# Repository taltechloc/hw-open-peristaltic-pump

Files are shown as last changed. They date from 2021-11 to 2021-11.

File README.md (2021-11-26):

# Open peristaltic microfluidic pump

## Features:
- Peristaltic pump
- Cheap and easy to assemble
- Wireless control
- Battery power

*Designed by: Martin Grosberg.*
*Please be kind and cite me if you use my designs:*
- Original source: Low-cost wireless smart microfluidic pump based on [Martin Grosberg's thesis](https://digikogu.taltech.ee/et/Item/b4fc732c-1057-41ed-a8f3-72b04feb9e4f).

## Construction and use

Folders: 
- Documentation: **Please read the user manual under the Documentation folder first!**
- Electronics: schematics and BOM
- Firmware: Arduino source code
- Mechanical: STL files for 3D printing. Use an FDM printer such as a [Prusa](https://www.prusa3d.com/category/3d-printers/). 

Please note that we cannot offer support or take responsibility for damage caused by using this product.

---


*This is an OSHW project*

OSHW logo

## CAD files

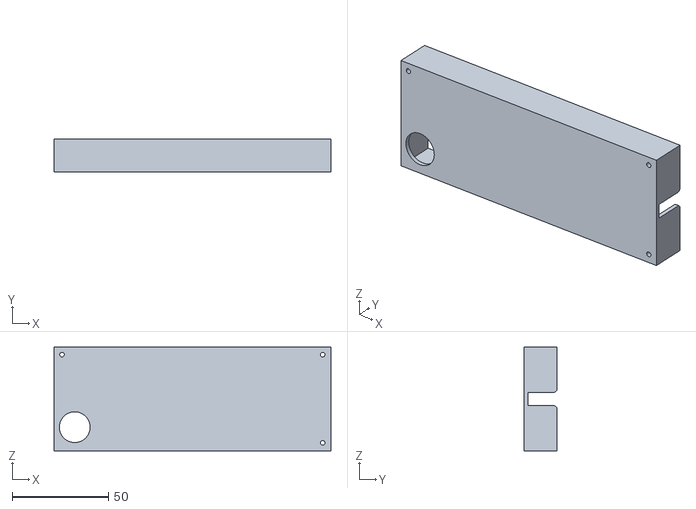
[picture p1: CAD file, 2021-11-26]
Mechanical/3D printing files/Flow sensor enclousure v8.STL
144.0 x 17.0 x 54.0

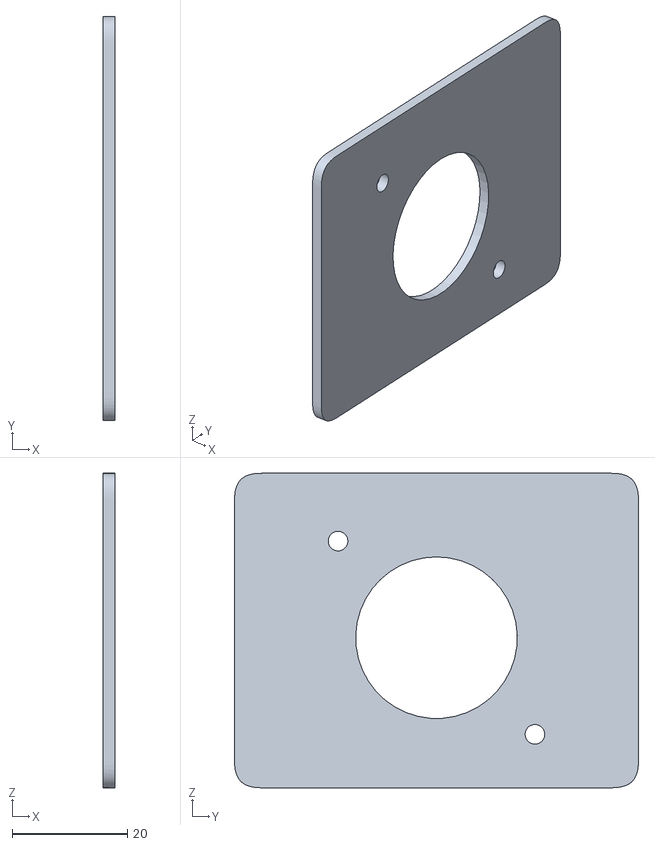
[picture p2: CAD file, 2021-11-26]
Mechanical/3D printing files/Motor plate.STL
2.00 x 70.0 x 54.5

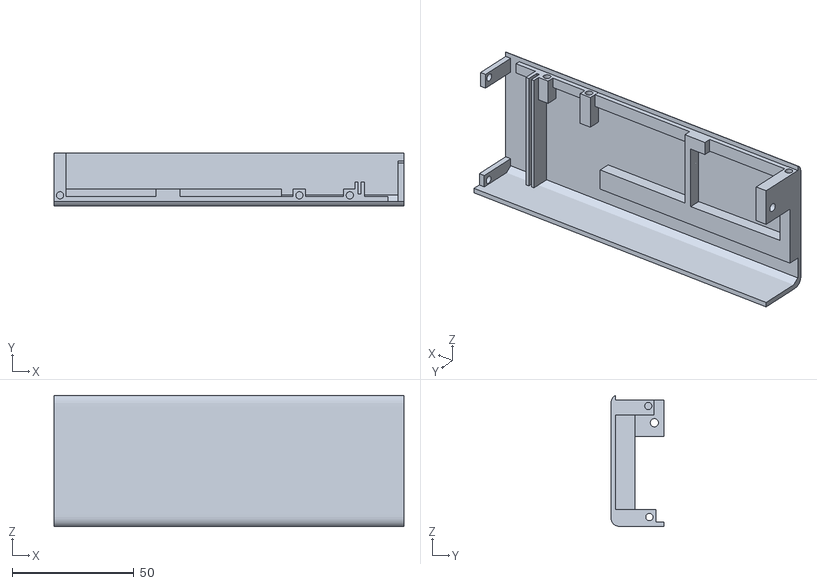
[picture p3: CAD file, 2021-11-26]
Mechanical/3D printing files/Electronics casing.STL
144.0 x 22.0 x 54.0

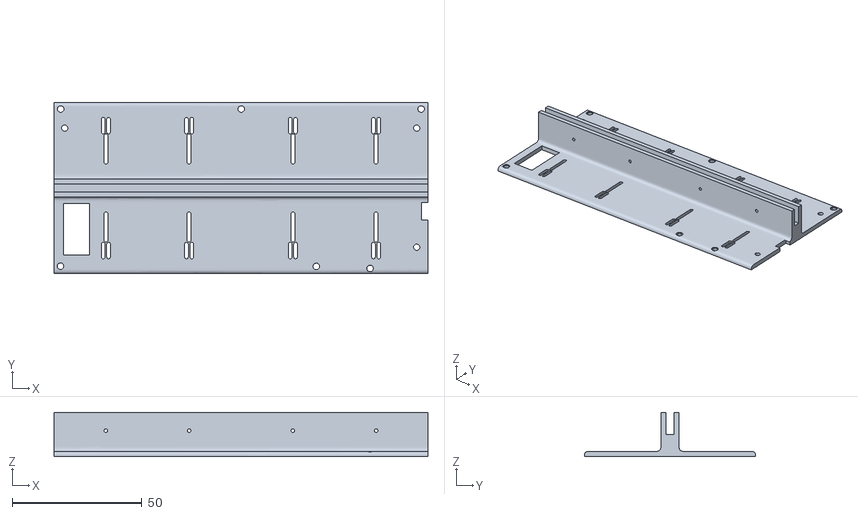
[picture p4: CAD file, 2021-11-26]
Mechanical/3D printing files/Front panel v8.STL
144.0 x 66.0 x 17.0

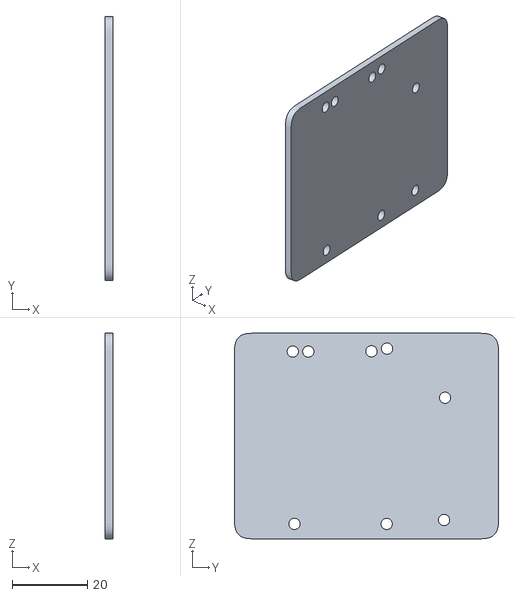
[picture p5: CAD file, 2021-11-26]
Mechanical/3D printing files/case v8.STL
2.00 x 70.0 x 54.5

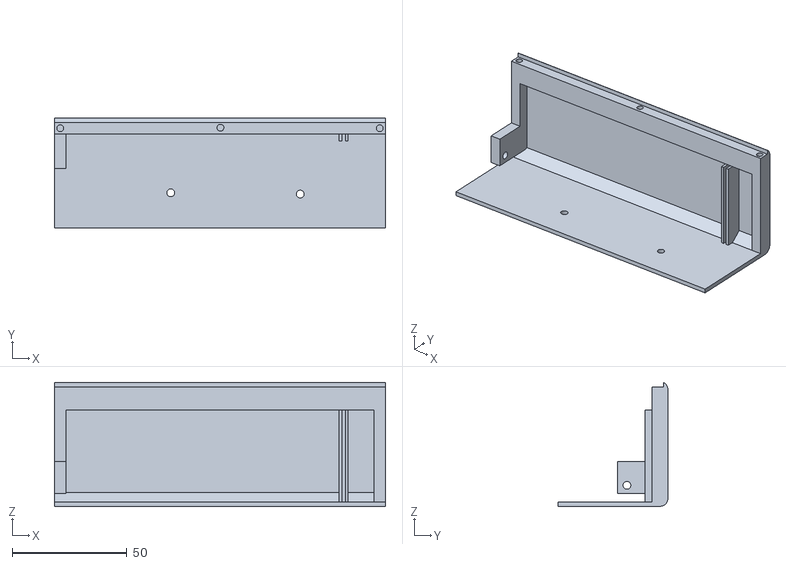
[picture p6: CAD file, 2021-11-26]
Mechanical/3D printing files/Casing.STL
144.0 x 48.0 x 54.0

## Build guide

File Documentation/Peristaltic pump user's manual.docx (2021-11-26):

Peristaltic pump

User’s Manual

# 1. Package contents

- 1. ESP32 DevkitC controller
- 2. Adafruit peristaltic pump
- 3. 18650 3.6V 3350 mAh Lithium-ion battery (2pcs), 18650 double battery holder
- 4. LM2596 DC/DC buck regulator
- 5. LM2577 DC/DC step up module
- 6. Prototyping board, 1N4007 rectifier diode, 2 1k resistors, 10k resistor, LMC7101 opamp, IRF520N MOSFET (Components needs to be soldered together).
- 7. ON-OFF button
- 8. headers and pins
- 9. Wires
- 10. Bolts and nuts
- 11. 3D printed enclousre

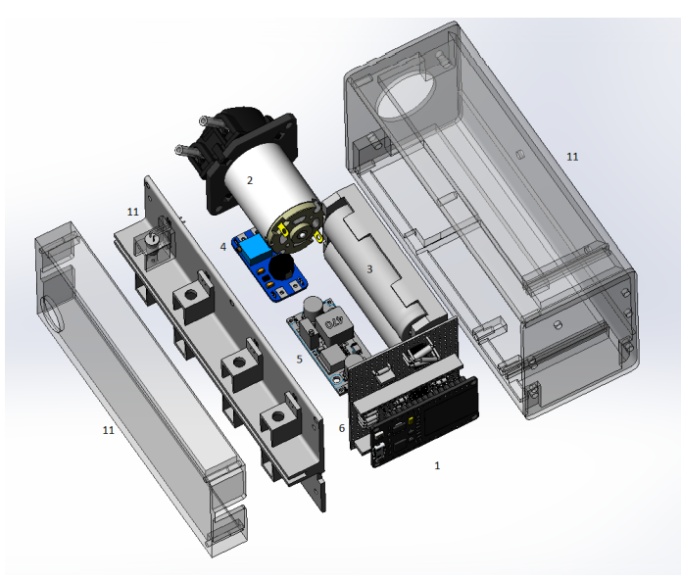
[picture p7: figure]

# 2. Safety precautions

- Solder the prototyping board components according to the schematics.
- Do wiring so that they will not becaume loose or short circuit the board.
- Upload the code through cable to the ESP32 devkitC controller. For safety reasons don’t have it connected with external batteries while uploading the code.
- Connect the EPS32 DevkitC controller right way on the prototyping board otherwise the board will get damaged.
- The batteries are connected parallel so the device usage time will be longer.
- When batteries are empty remove the case carefully and put them to charging station. After fully charged connect them them the right way. It’s good to put some polarity stickers to battery holder.

# 3. Features

- User Interface over Wi-Fi AP
- Possible to add two slave pumps
- Timer function

# 4. Technical description

- Flow rate 12-72 ml/min
- Tubing ID: 1mm
- Runtime 10-15min at max flow rate
- Power ON/OFF
- 18650 lithium-ion batteries (2pcs)
- Dimensions: 70x71,50x174,20(mm)

# 5. Connection and operation

- Before operating be sure to have fully charged batteries. In order to charge it’s needed to open the device enclousure. The charging station is not included. When putting back batteries, then the batteries are connected in parallel.
- Turn the pump on from ON/OFF button
- Use a laptop or mobile phone and connect to „SmartFlowController2“.
- Enter password: „Taltech2020“
- Set the flow rate and pumping time.
- Connect one tubing to reservoir and the 2nd tube end to the lab-on-the-chip.
- When you have a slave pump, then it’s possible to add it int the interface by entering the MAC ID.

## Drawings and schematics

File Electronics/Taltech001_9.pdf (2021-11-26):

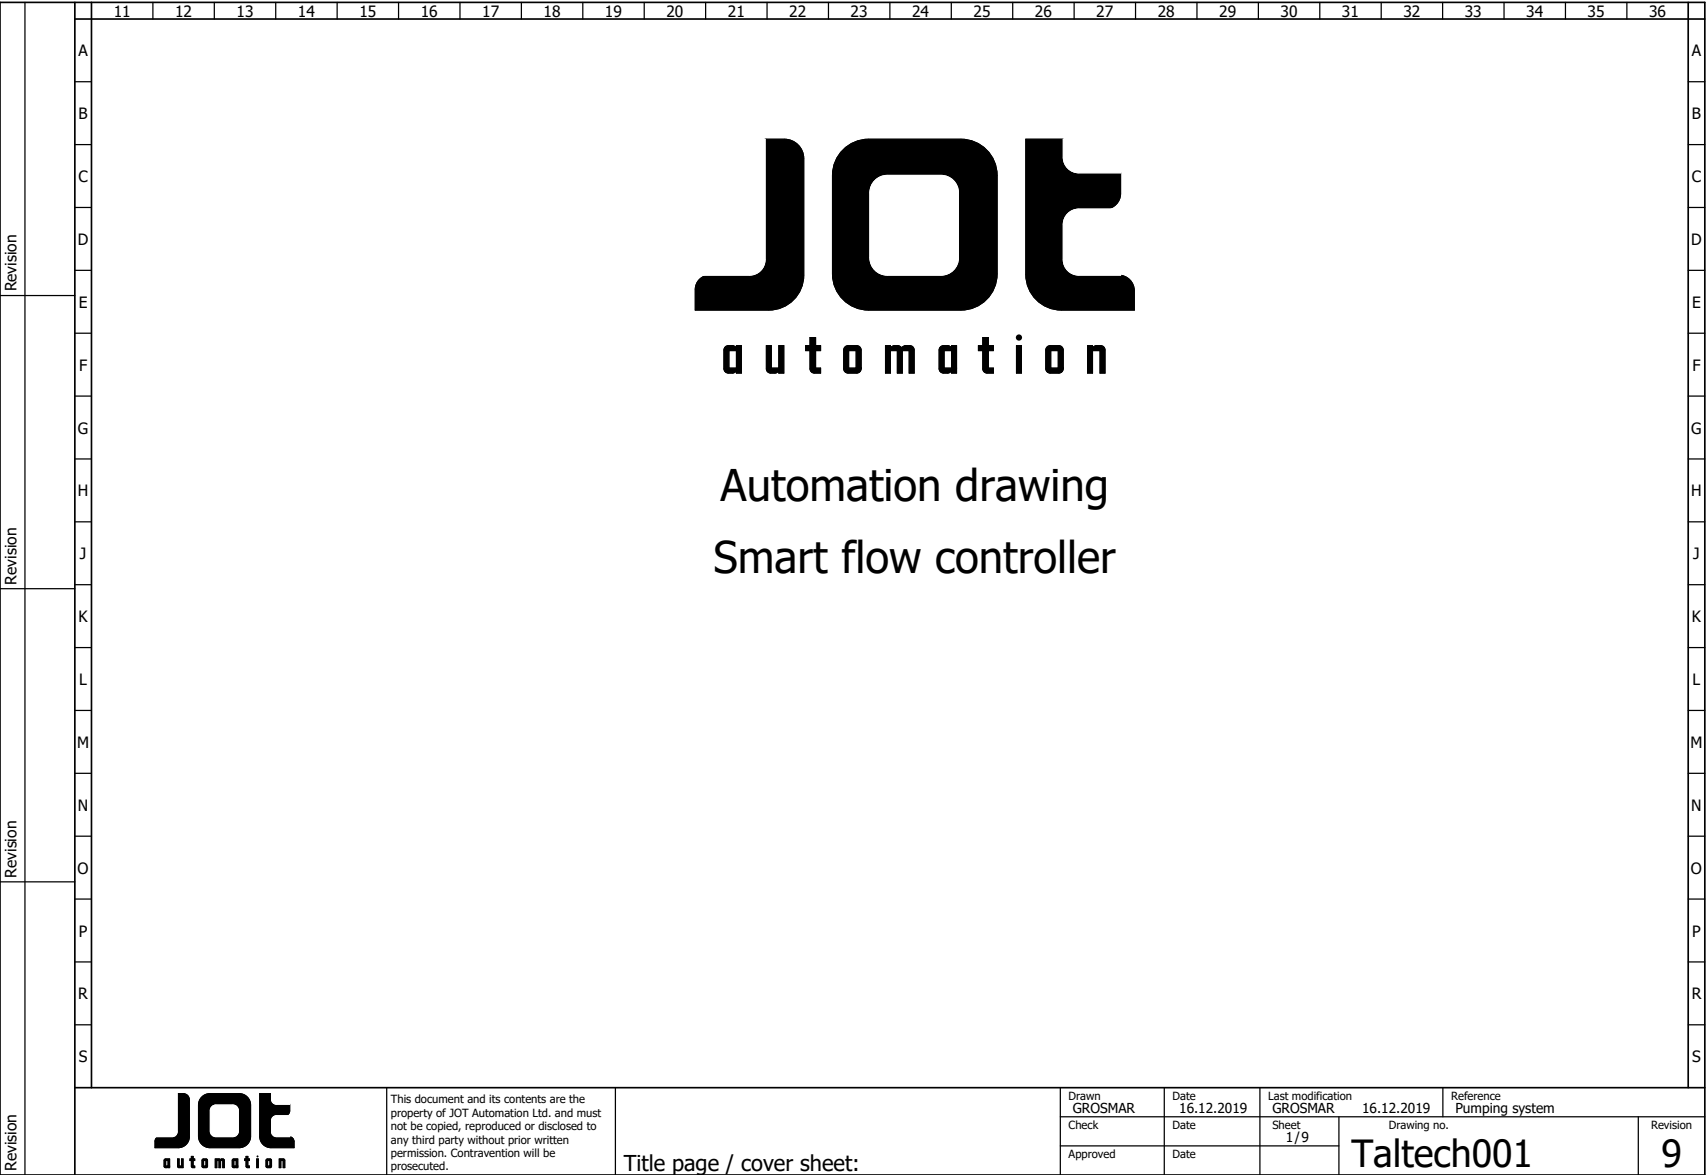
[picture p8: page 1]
Revision; Revision Revision

Automation drawing
Smart flow controller

This document and its contents are the property of JOT Automation Ltd. and must not be copied, reproduced or disclosed to prosecuted. any third party without prior written permission. Contravention will be | Title page / cover sheet: | Drawn GROSMAR | Date 16.12.2019 | Last modification GROSMAR 16.12.2019 | Reference Pumping system

Check | Sheet | Drawing no. Taltech001 / | Revision

Approved

# Revision overview

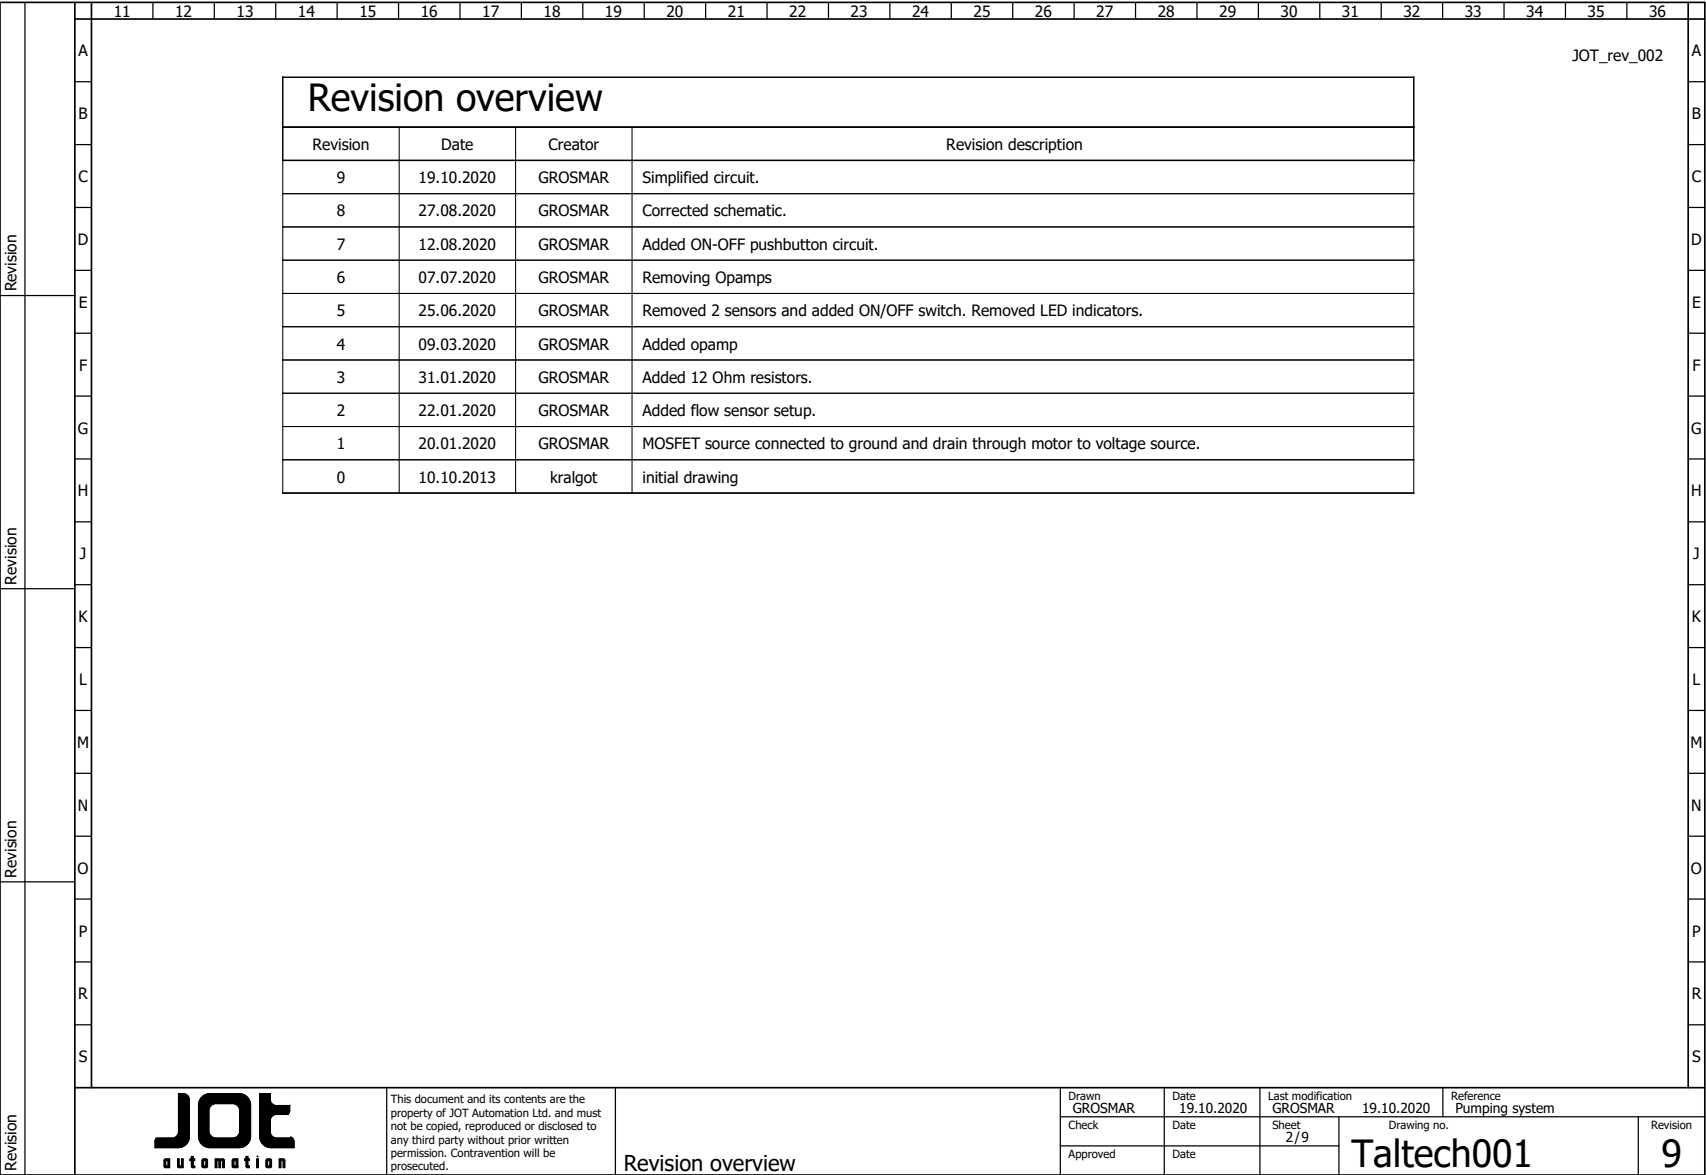
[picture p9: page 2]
Revision; Revision Revision; JOT_rev_002; GROSMAR; Added flow sensor setup.; MOSFET source connected to ground and drain through motor to voltage source.; kralgot; initial drawing

Revision | Date | Creator | Revision description

9 | 19.10.2020 | GROSMAR | Simplified circuit.

8 | 27.08.2020 | GROSMAR | Corrected schematic.

7 | 12.08.2020 | GROSMAR | Added ON-OFF pushbutton circuit.

6 | 07.07.2020 | GROSMAR | Removing Opamps

5 | 25.06.2020 | GROSMAR | Removed 2 sensors and added ON/OFF switch. Removed LED indicators.

4 | 09.03.2020 | GROSMAR | Added opamp

3 | 31.01.2020 | GROSMAR | Added 12 Ohm resistors.

Revision overview | 19.10.2020 | GROSMAR 19.10.2020

| DRAWING INDEX

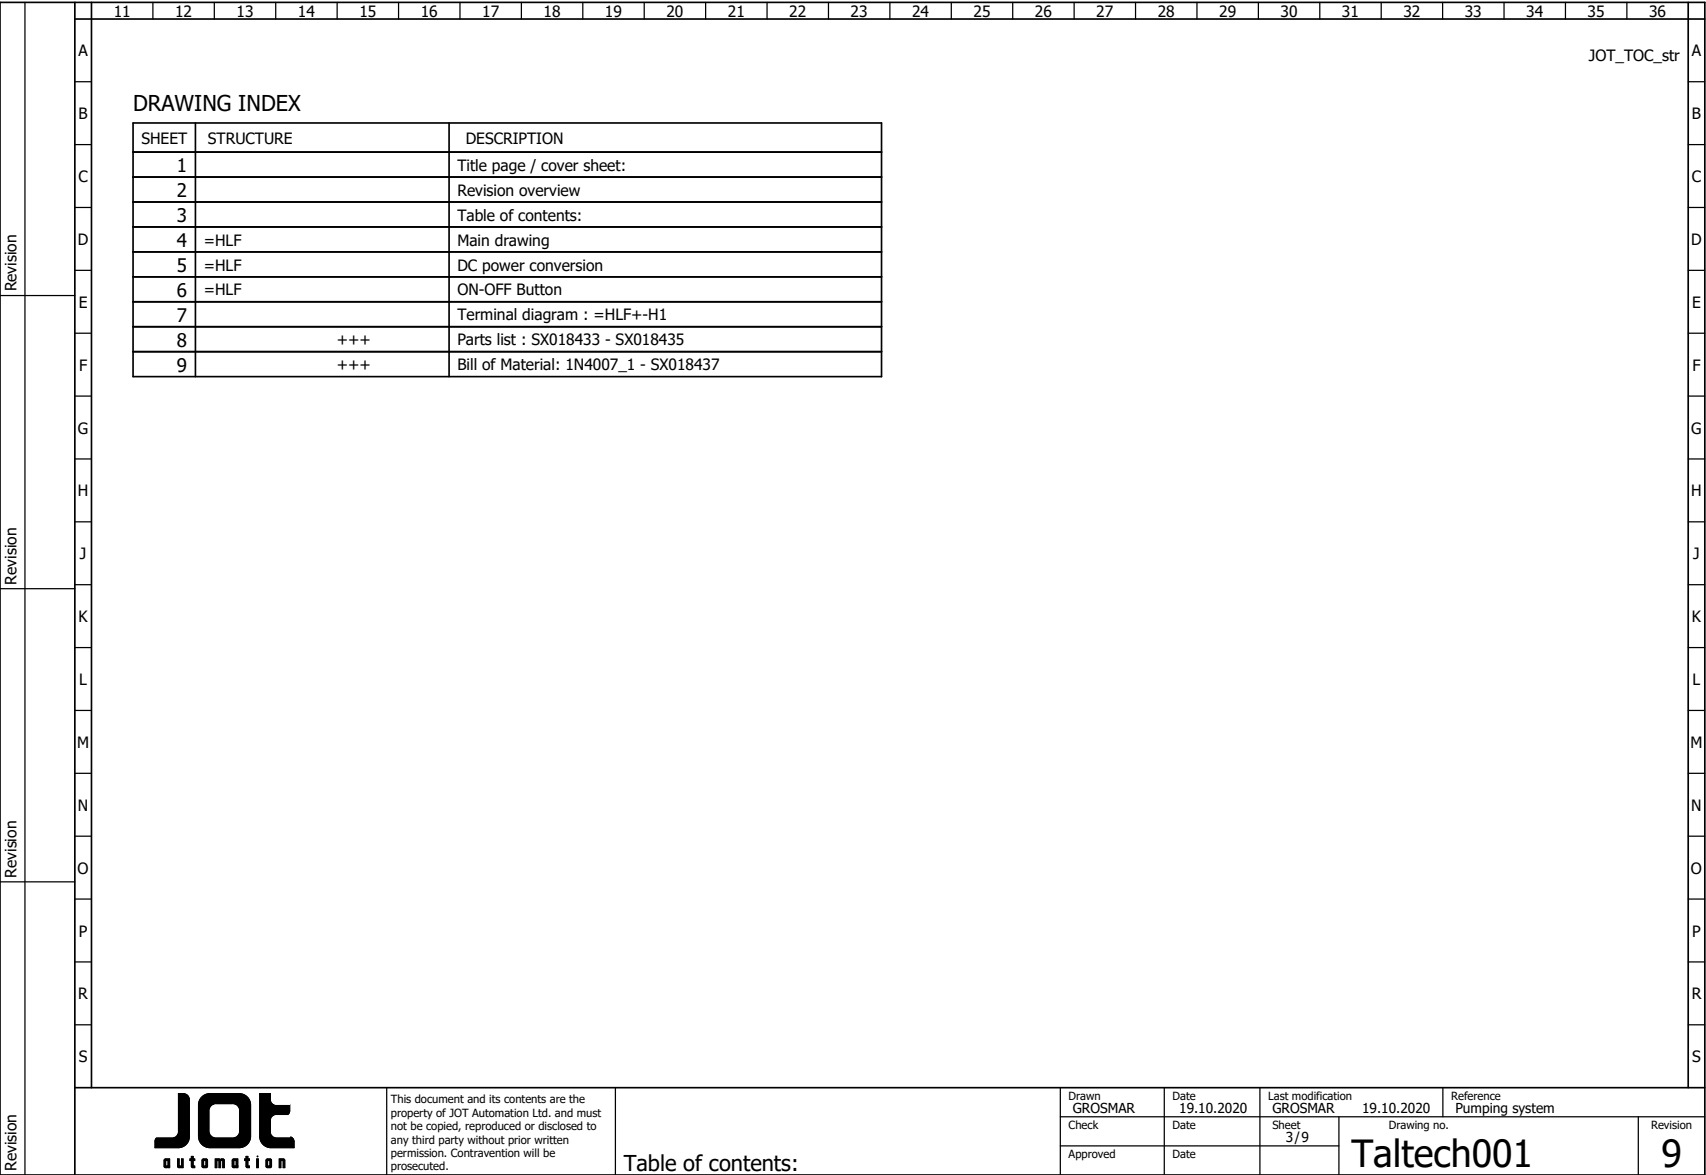
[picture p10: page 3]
Revision; Revision Revision; JOT_TOC_str

SHEET | STRUCTURE | DESCRIPTION
1 | | Title page / cover sheet:
2 | | Revision overview
3 | | Table of contents:
4 | =HLF | Main drawing
5 | =HLF | DC power conversion
6 | =HLF | ON-OFF Button
7 | | Terminal diagram : =HLF+-H1
8 | +++ | Parts list : SX018433 - SX018435
9 | +++ | Bill of Material: 1N4007_1 - SX018437

Table of contents:

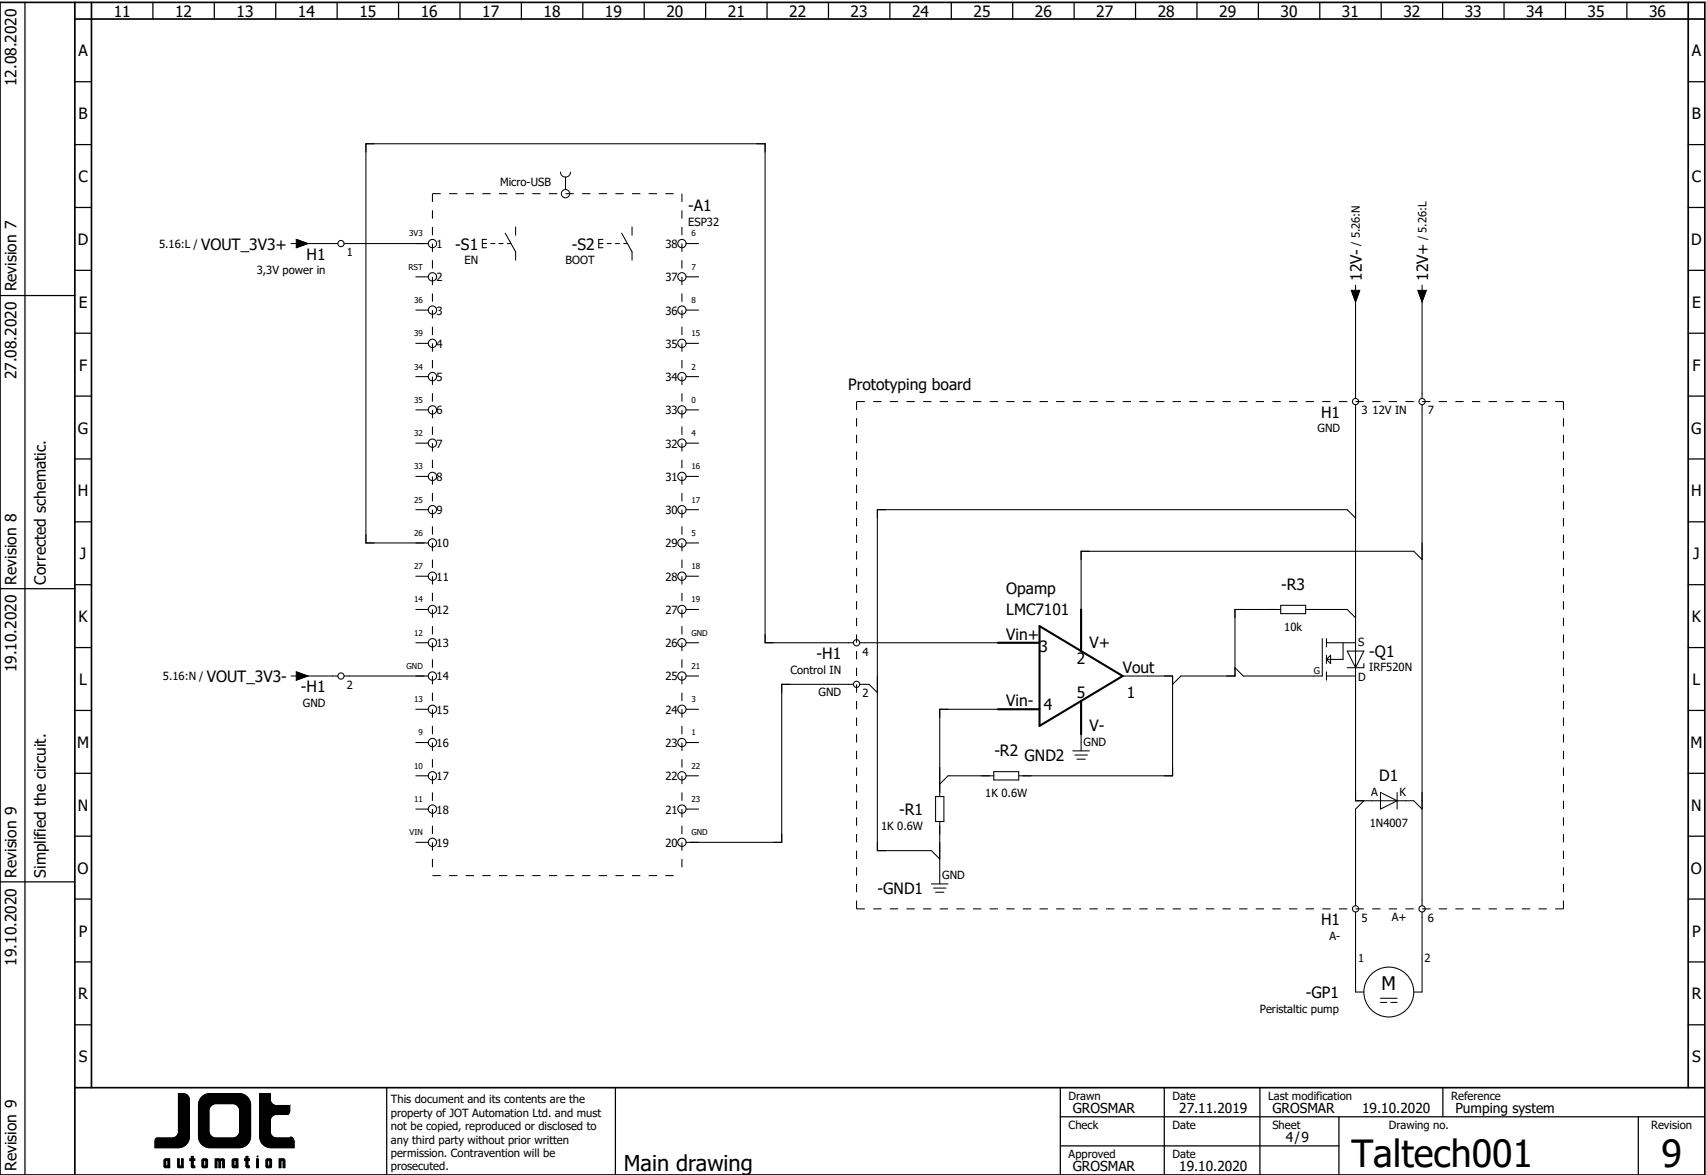
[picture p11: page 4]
Revision; Corrected schematic.; 19.10.2020 Revision; 7 Revision; Vin+; Vin-; Vout; Prototyping board; LMC7101; Opamp; IRF520N; ESP32; RST; GND; VIN; Peristaltic pump; Micro-USB; BOOT; -GND1; GND2; Control IN; 3,3V power in; 5.16:L / VOUT_3V3+; 5.16:N / VOUT_3V3-

Simplified the circuit.

Main drawing | 27.11.2019

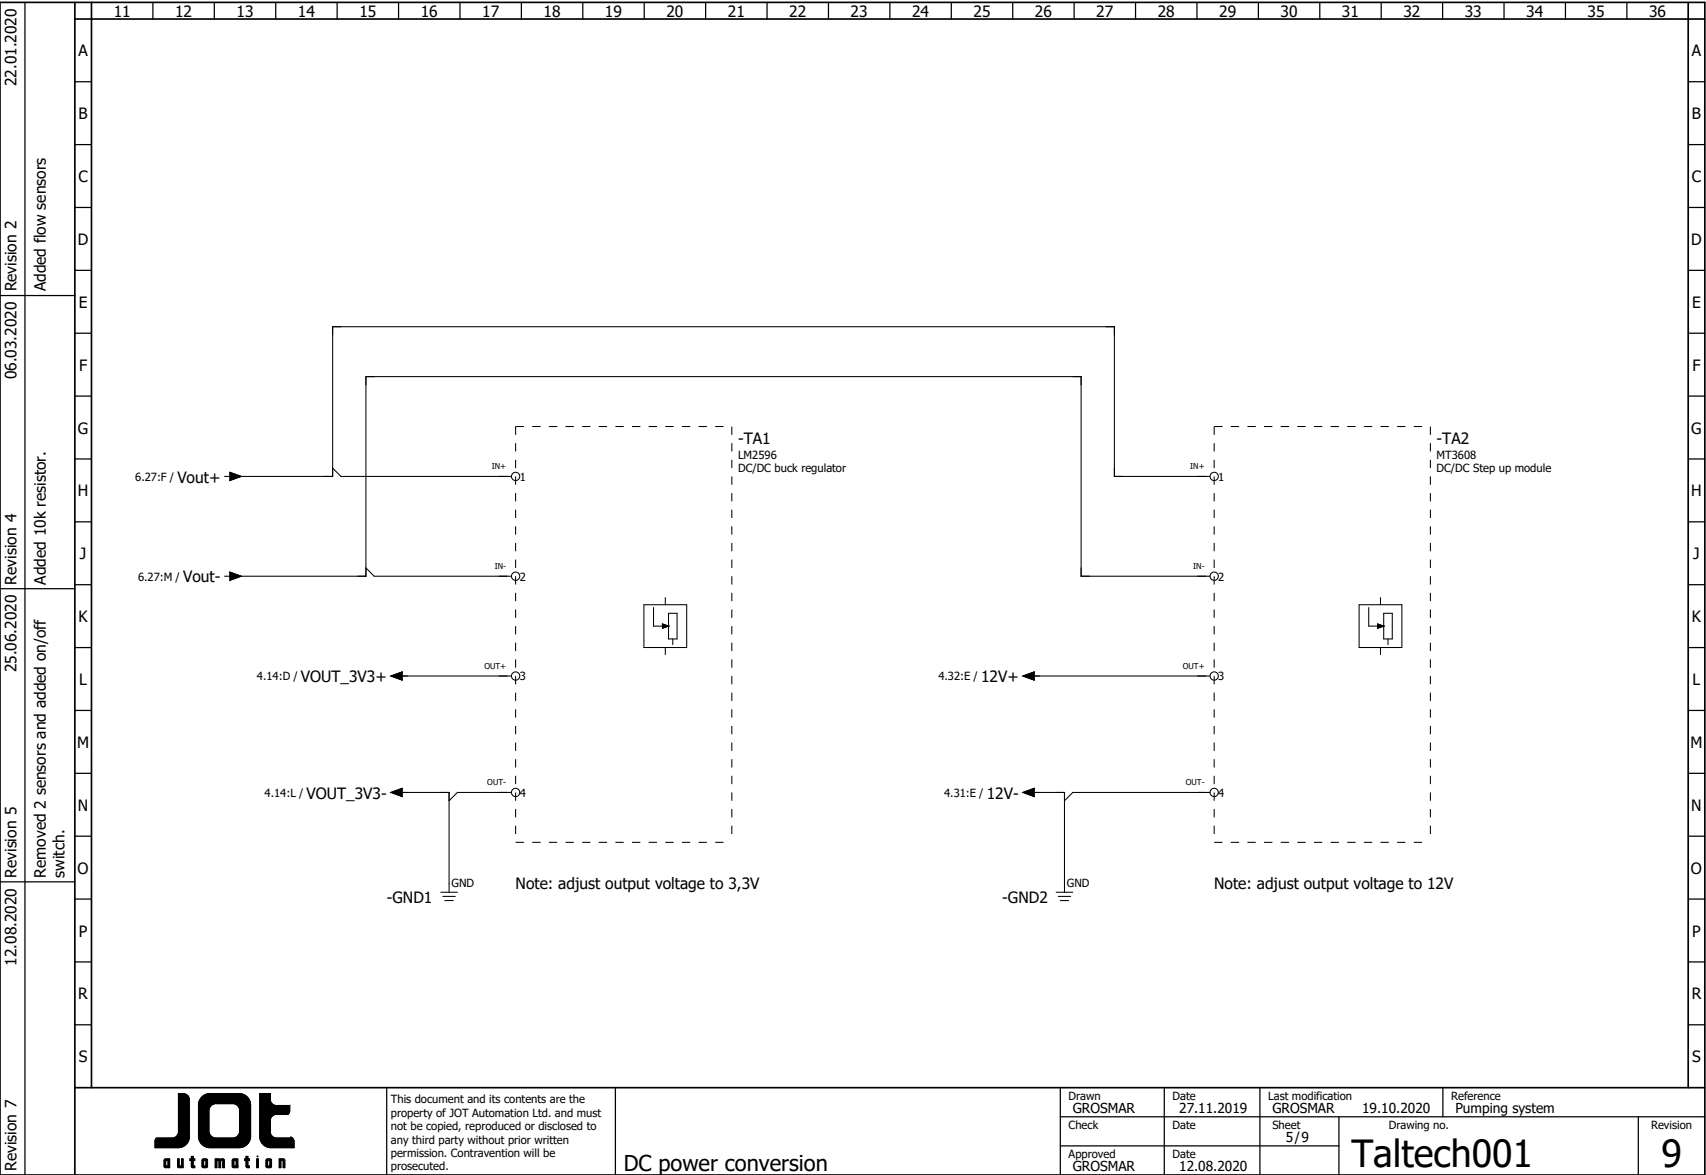
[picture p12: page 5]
Revision; 12.08.2020 Revision; switch.; 2 Revision; Note: adjust output voltage to 3,3V; Note: adjust output voltage to 12V; OUT+; OUT-; DC/DC Step up module; GND; -GND2; -GND1; 4.14:D / VOUT_3V3+; 4.14:L / VOUT_3V3-; 6.27:F / Vout+; 6.27:M / Vout-

Added 10k resistor. Added flow sensors

DC/DC buck regulator IN+

Removed 2 sensors and added on/off

DC power conversion | 27.11.2019

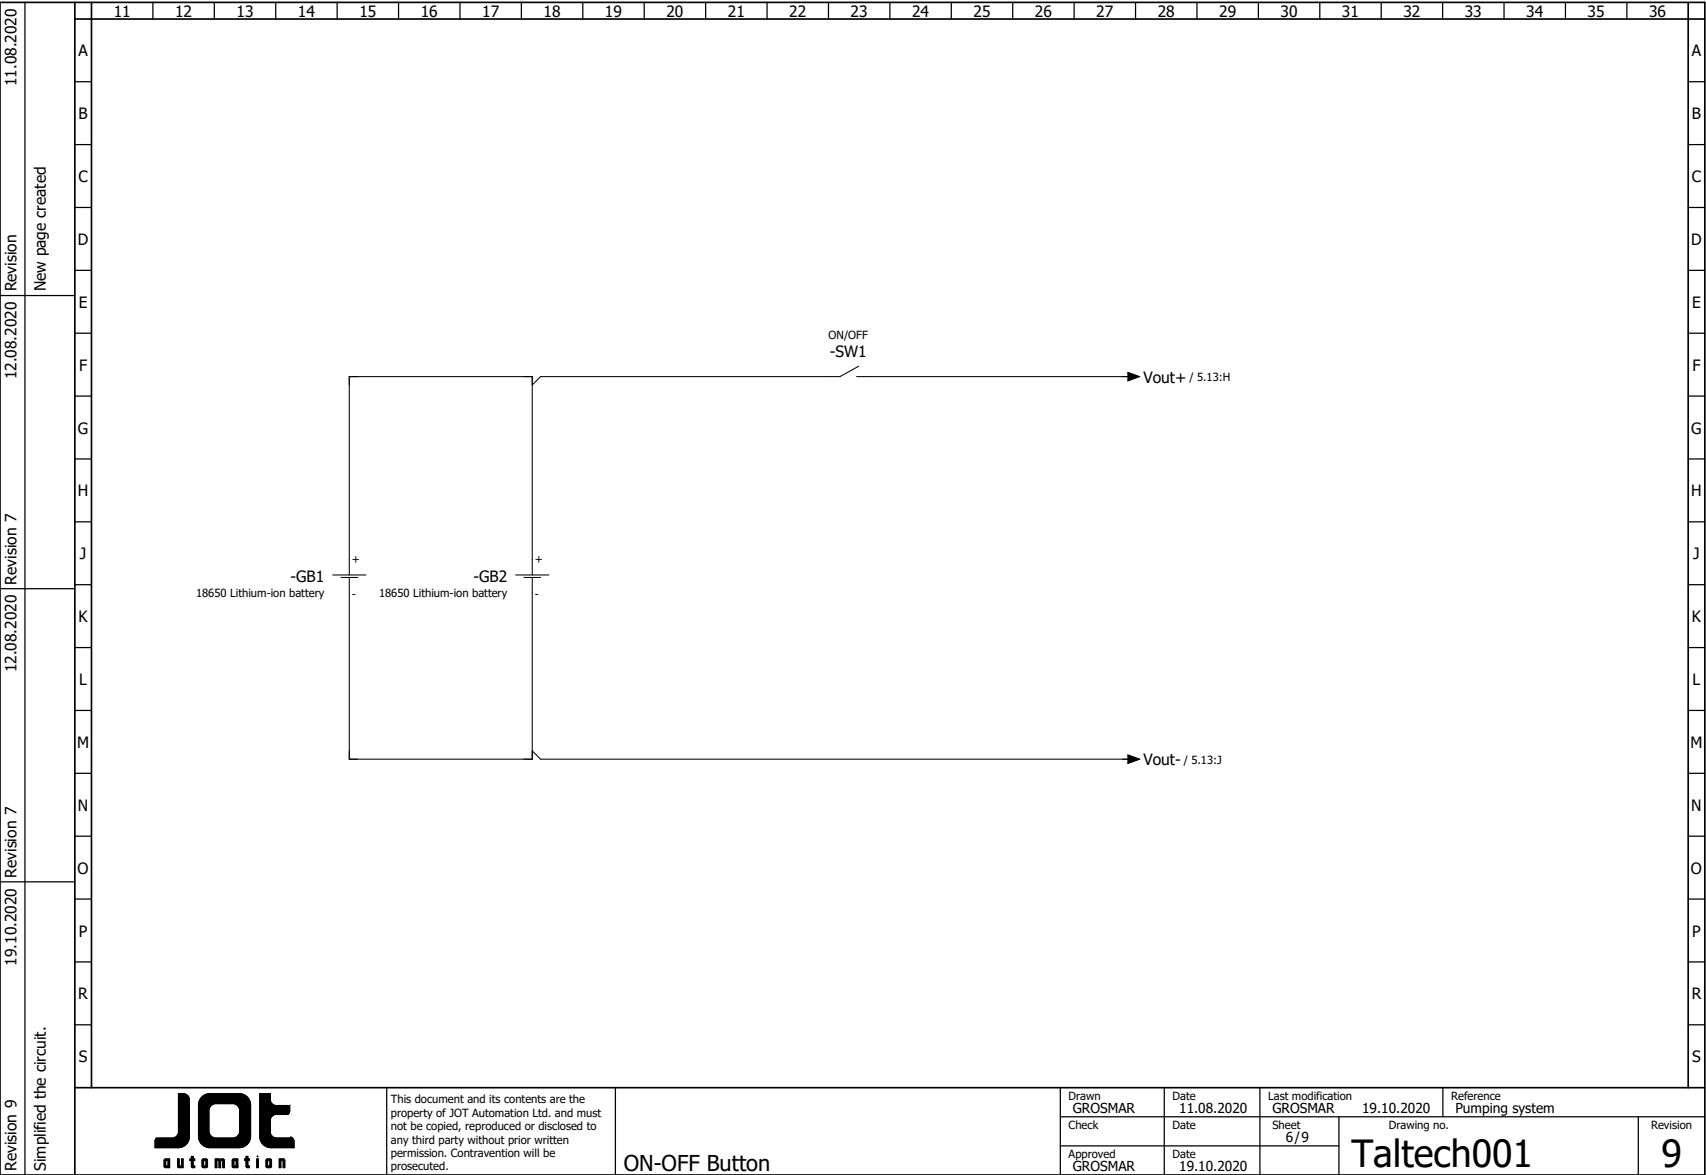
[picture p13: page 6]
Revision; 19.10.2020 Revision; Revision 12.08.2020; 7 Revision; ON/OFF; Vout+ / 5.13:H; Vout- / 5.13:J

New page created

18650 Lithium-ion battery

Simplified the circuit.

ON-OFF Button | 11.08.2020

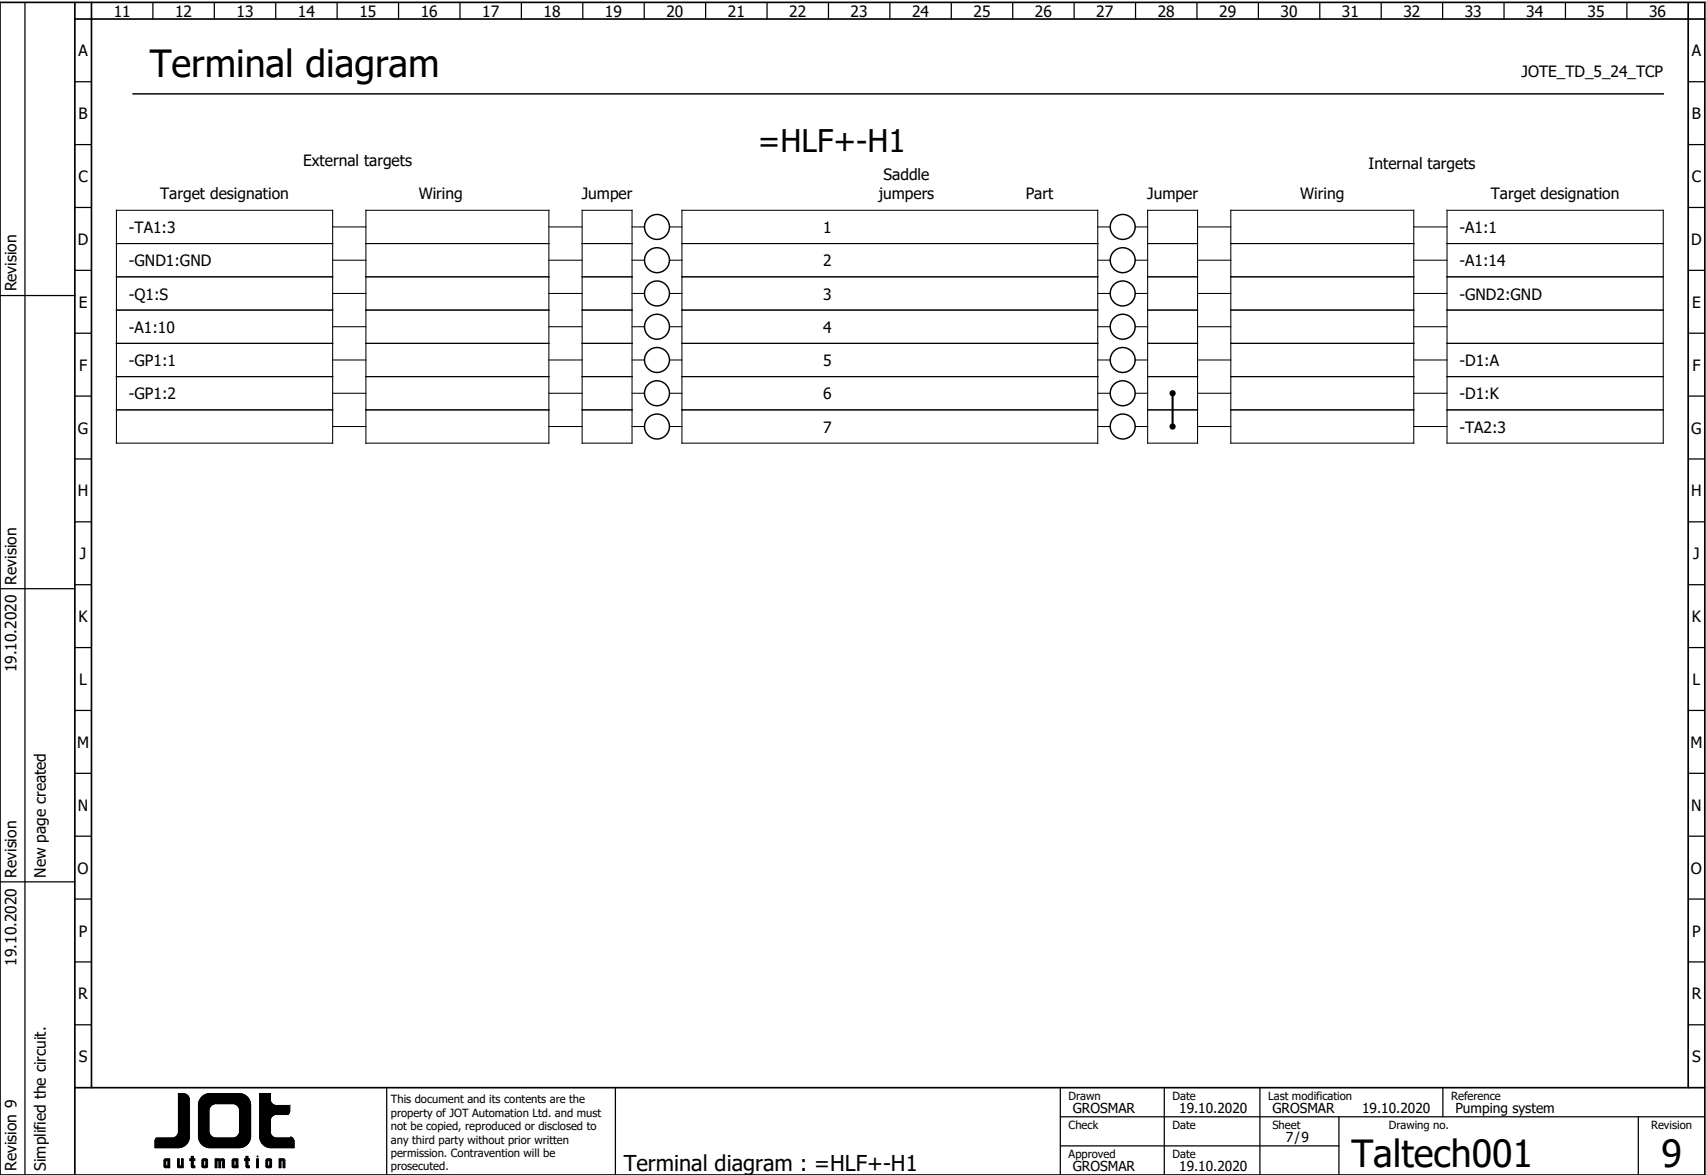
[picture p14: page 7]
Revision; 19.10.2020 Revision; 9 Revision; -GND1:GND; -GND2:GND

Terminal diagram JOTE_TD_5_24_TCP =HLF+-H1 External targets Internal targets Saddle Target designation Wiring Jumper jumpers Part Jumper Wiring Target designation

New page created

Simplified the circuit.

Terminal diagram : =HLF+-H1

# COMPONENT LIST

PART | COMPONENT NR. | JOT CODE | PCS | PAGE-PATH | TYPE | MANUFACTURER

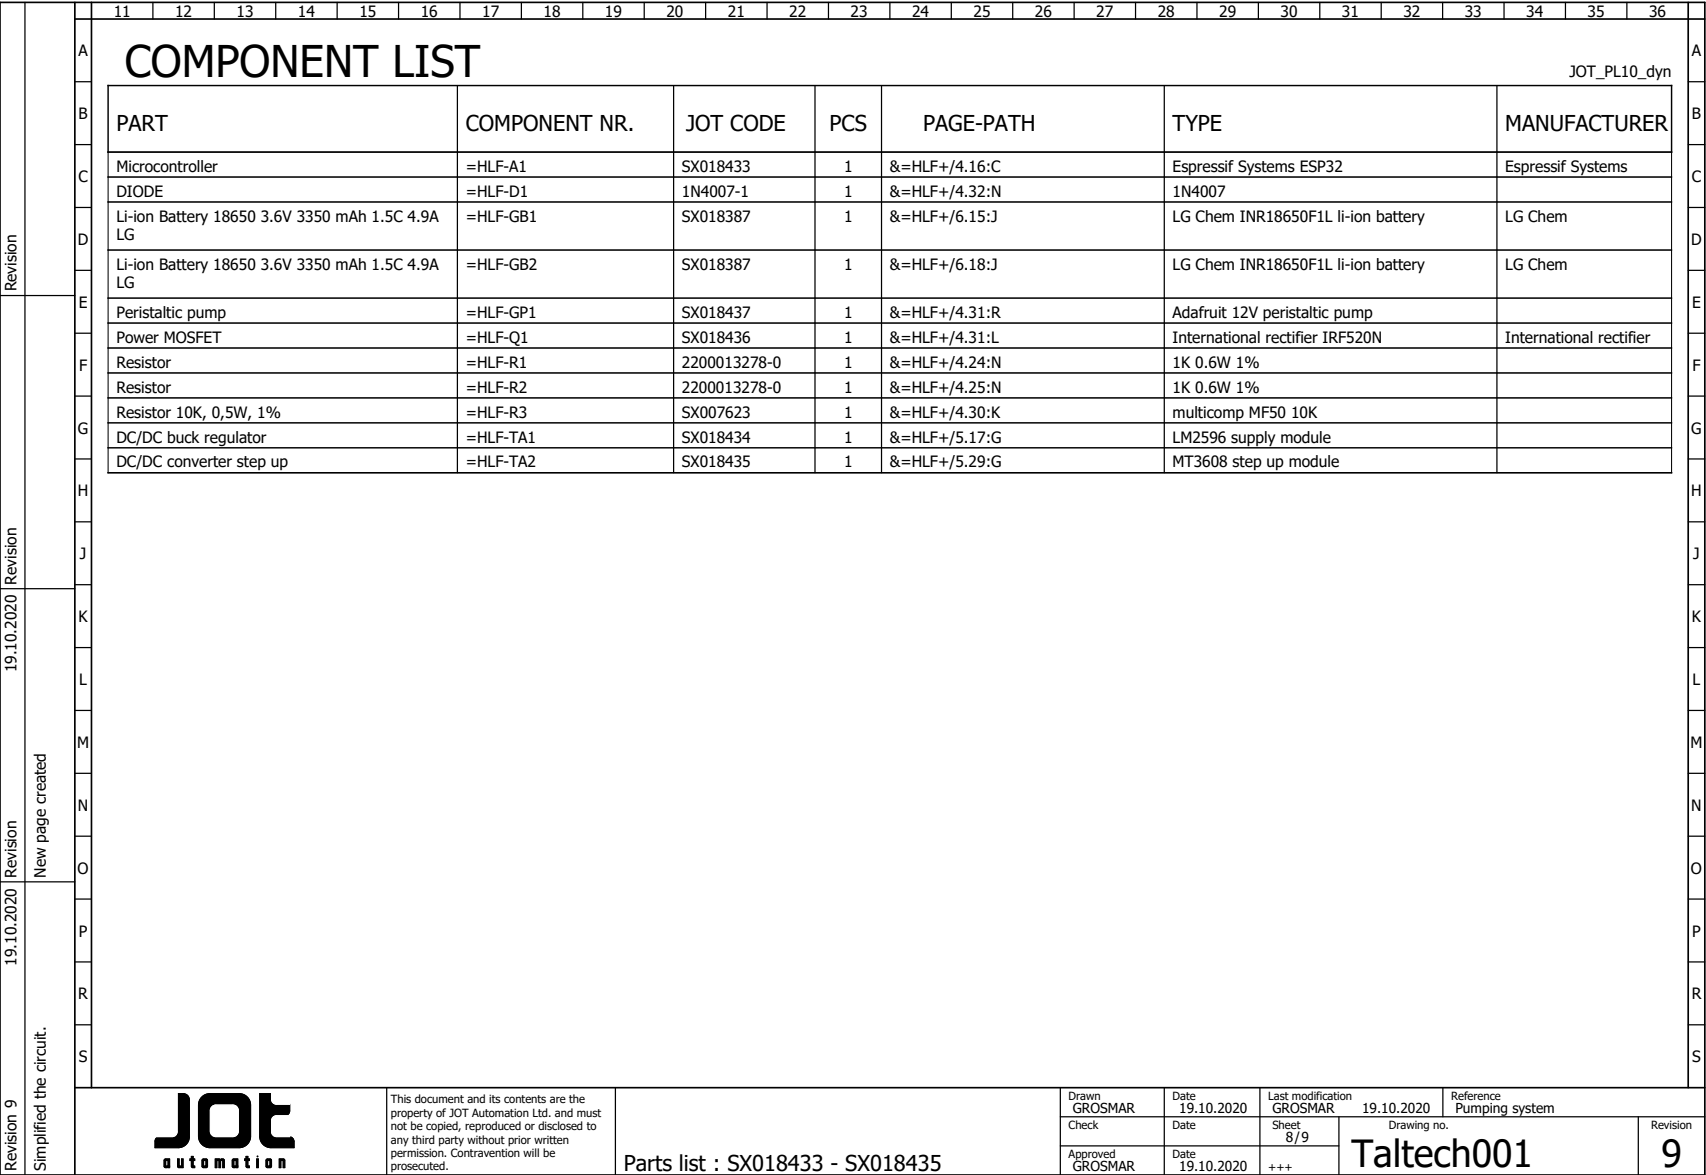
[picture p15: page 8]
Revision; 19.10.2020 Revision; 9 Revision; JOT_PL10_dyn; Resistor 10K, 0,5W, 1%; =HLF-R3; &=HLF+/4.30:K; multicomp MF50 10K

Microcontroller | =HLF-A1 | SX018433 | 1 | &=HLF+/4.16:C | Espressif Systems ESP32 | Espressif Systems
DIODE | =HLF-D1 | 1N4007-1 | 1 | &=HLF+/4.32:N | 1N4007
Li-ion Battery 18650 3.6V 3350 mAh 1.5C 4.9A LG | =HLF-GB1 | SX018387 | 1 | &=HLF+/6.15:J | LG Chem INR18650F1L li-ion battery | LG Chem

Li-ion Battery 18650 3.6V 3350 mAh 1.5C 4.9A LG | =HLF-GB2 | SX018387 | 1 | &=HLF+/6.18:J | LG Chem INR18650F1L li-ion battery | LG Chem

Peristaltic pump | =HLF-GP1 | SX018437 | 1 | &=HLF+/4.31:R | Adafruit 12V peristaltic pump
Power MOSFET | =HLF-Q1 | SX018436 | 1 | &=HLF+/4.31:L | International rectifier IRF520N | International rectifier
Resistor | =HLF-R1 | 2200013278-0 | 1 | &=HLF+/4.24:N | 1K 0.6W 1%
Resistor | =HLF-R2 | 2200013278-0 | 1 | &=HLF+/4.25:N | 1K 0.6W 1%

DC/DC buck regulator | =HLF-TA1 | SX018434 | 1 | &=HLF+/5.17:G | LM2596 supply module
DC/DC converter step up | =HLF-TA2 | SX018435 | 1 | &=HLF+/5.29:G | MT3608 step up module

New page created

Simplified the circuit.

Parts list : SX018433 - SX018435

| Bill of Material JOT_PLG_CL
JOT CODE | PART | TYPE | Qty. | Unit | MANUFACTURER

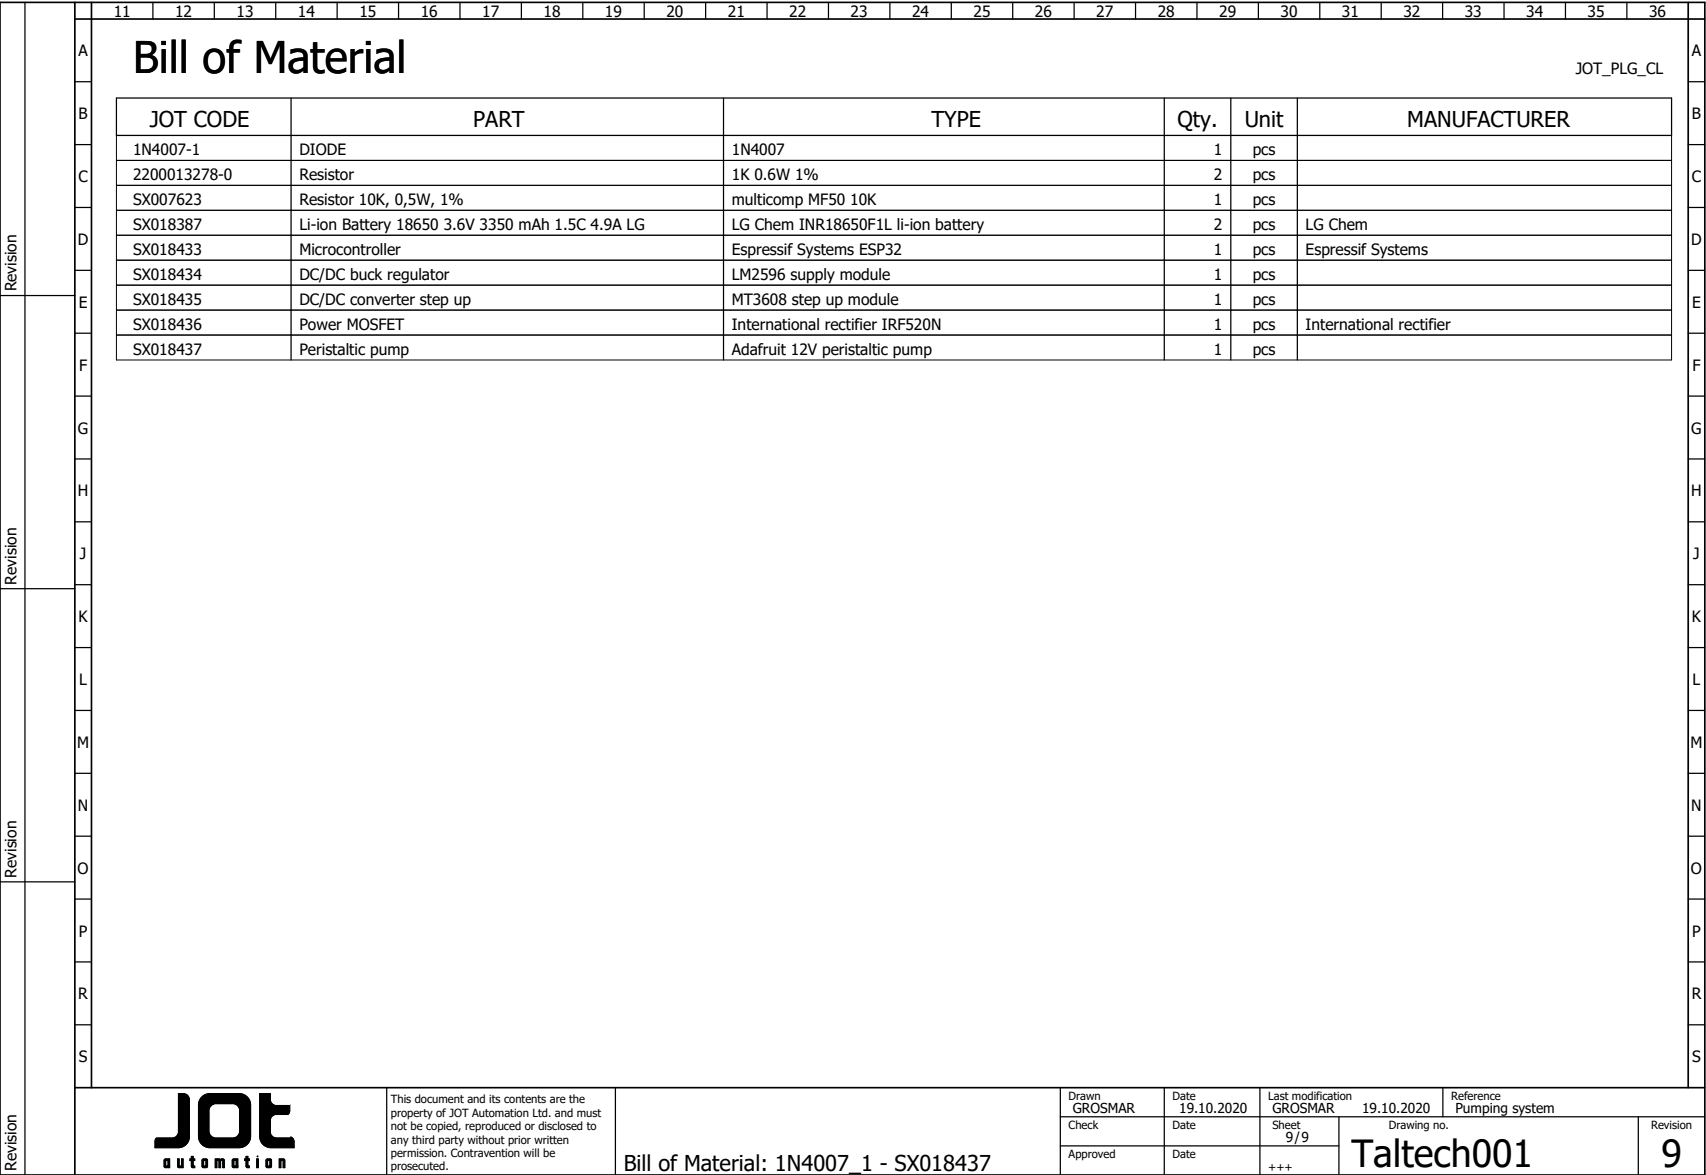
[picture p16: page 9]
Revision; Revision Revision; Li-ion Battery 18650 3.6V 3350 mAh 1.5C 4.9A LG; LG Chem INR18650F1L li-ion battery; pcs; LG Chem; Peristaltic pump; Adafruit 12V peristaltic pump
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

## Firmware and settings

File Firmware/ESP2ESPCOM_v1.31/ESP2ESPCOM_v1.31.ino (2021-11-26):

/*
 Create a WiFi access point and provide a web server on it. 
For tutorial video of this code, watch out this video
https://youtu.be/fcmb_3aBfH4
  visit 
  http://www.techiesms.com
  for IoT project tutorials.
  
        #techiesms
  explore | learn | share
*/

// Import required libraries
#ifdef ESP32
  #include <ArduinoJson.h>
  #include <WiFi.h>
  #include <SPIFFS.h>
  #include <ESPAsyncWebServer.h>
  /*
  //#include <WebSocketsServer.h>
#else
  #include <Arduino.h>
  #include <ESP8266WiFi.h>
  #include <Hash.h>
  #include <ESPAsyncTCP.h>
  #include <ESPAsyncWebServer.h>
  #include <FS.h>*/
#endif

#include <esp_now.h>
#include "ESPNOW.h"
#include "MACaddress.h"

#define DEBUG true
#define DEBUG2 false

/*Communication specific variable*/
/* Set these to your desired credentials. */
const char *ssid = "SmartFlowController2"; // You can change it according to your ease
const char *password = "Taltech2020"; // You can change it according to your ease
/* Put IP Address details */
IPAddress local_ip(192,168,5,1);
IPAddress gateway(192,168,5,1);
IPAddress subnet(255,255,255,0);
//const char* PARAM_MESSAGE = "message";
const int dns_port = 53;
const int http_port = 80;
//const int ws_port = 1337;//websocket port

char msg_buf[15];
int pumpState = 0;

/*Webserver*/
AsyncWebServer server(http_port); // establishing server at port 80 (HTTP protocol's default port)
AsyncWebSocket webSocket("/ws");
//ESP-NOW

struct_message myData[3];

// REPLACE WITH YOUR RECEIVER MAC Address
uint8_t broadcastAddress1[] = {0x4C, 0x11, 0xAE, 0xEA, 0xEE, 0xE8};
uint8_t broadcastAddress2[] = {0xFF, 0xFF, 0xFF, 0xFF, 0xFF, 0xFF};
uint8_t broadcastAddress3[] = {0xFF, 0xFF, 0xFF, 0xFF, 0xFF, 0xFF};

#define NUMSLAVES 3
esp_now_peer_info_t slaves[NUMSLAVES] = {};

int flow=50;
int settime=50;
const int resolution = 12;
const int ledChannel = 1;
const int freq = 5000;

bool mrunning = true;

const int PWMPin=26;
int setpoint=2000;

unsigned long previousMillis=millis();
unsigned long currentMillis=millis();

bool sendData(int nr) {
  const uint8_t *peer_addr = slaves[nr].peer_addr;
    esp_err_t result = esp_now_send(peer_addr,(uint8_t *)&myData[nr], sizeof(myData[nr]));
    Serial.print("Send Status: ");
    if (result == ESP_OK) {
      Serial.println("Success");
      return true;
    } else if (result == ESP_ERR_ESPNOW_NOT_INIT) {
      // How did we get so far!!
      Serial.println("ESPNOW not Init.");
      return false;
    } else if (result == ESP_ERR_ESPNOW_ARG) {
      Serial.println("Invalid Argument");
      return false;
    } else if (result == ESP_ERR_ESPNOW_INTERNAL) {
      Serial.println("Internal Error");
      return false;
    } else if (result == ESP_ERR_ESPNOW_NO_MEM) {
      Serial.println("ESP_ERR_ESPNOW_NO_MEM");
      return false;
    } else if (result == ESP_ERR_ESPNOW_NOT_FOUND) {
      Serial.println("Peer not found.");
      return false;
    } else {
      Serial.println("Not sure what happened");
      return false;
    }
    delay(100);
}
// Initilizeing ESPNOW and checking if the device is paired, if not, then it's going to be paired.
bool PairWithDevice(uint8_t Address[], int nrPump)
{
  InitESPNow();
  // Once ESPNow is successfully Init, we will register for Send CB to
  // get the status of Trasnmitted packet
  Serial.println("Entering esp_now_register_send_cb");
  esp_now_register_send_cb(OnDataSent);

  Serial.println("Registering peer");
  // Register peer

  memcpy(slaves[nrPump].peer_addr, Address, 6);
  slaves[nrPump].channel = 0;  
  slaves[nrPump].encrypt = false;

  // check if the peer exists
  bool exists = esp_now_is_peer_exist(slaves[nrPump].peer_addr);
  if (exists) {
    // Slave already paired.
    Serial.println("Already Paired");
  }
  else{
  Serial.println("Adding peer");
  // Add peer
  // Slave not paired, attempt pair
  esp_err_t addStatus = esp_now_add_peer(&slaves[nrPump]);        
  if (addStatus = ESP_OK){
    Serial.print("Pairing with device was succesful.");
    return true;
  } else if (addStatus == ESP_ERR_ESPNOW_NOT_INIT) {
    // How did we get so far!!
    Serial.println("ESPNOW Not Init");
    return false;
  } else if (addStatus == ESP_ERR_ESPNOW_ARG) {
    Serial.println("Add Peer - Invalid Argument");
    return false;
  } else if (addStatus == ESP_ERR_ESPNOW_FULL) {
    Serial.println("Peer list full");
    return false;
  } else if (addStatus == ESP_ERR_ESPNOW_NO_MEM) {
    Serial.println("Out of memory");
    return false;
  } else if (addStatus == ESP_ERR_ESPNOW_EXIST) {
    Serial.println("Peer Exists");
    return true;
  } else {
    Serial.println("Not sure what happened");// peerinfo must be global variable
    return false;
  }

  delay(100);
}
}

void SendMessageUser(bool input, AsyncWebSocketClient * client)
{
    if (input == true) {
    Serial.println("Sent with success to Pump2");
    sprintf(msg_buf, "%d", "Sent with success");
    Serial.printf("Sending to [%u]: %s\n", client, msg_buf);
    client->text(msg_buf);
  }
  else {
    Serial.println("Error sending data to Pump2");
    sprintf(msg_buf, "%d", "Error connecting or sending data to pump2");
    Serial.printf("Sending to [%u]: %s\n", client, "Error connecting or sending data to pump2");
    client->text("Error connecting or sending data to pump2");
  } 
}  
//char MACaddress(String input,char result[]);

// Callback: receiving any WebSocket message
void onWebSocketEvent(AsyncWebSocket * server, 
                      AsyncWebSocketClient * client, 
                      AwsEventType type, void * arg, 
                      uint8_t *data, size_t length) {
  // Figure out the type of WebSocket event
  switch(type) 
  {
    // Client has disconnected
    case WS_EVT_DISCONNECT:
      Serial.printf("[%u] Disconnected!\n", client);
      break;
    // New client has connected
    case WS_EVT_CONNECT:
      {
        //IPAddress ip = webSocket.remoteIP(client);
        Serial.printf("[%u] Connection from ", client);
        //Serial.println(ip.toString());
      }
      break;
    // Handle text messages from client
    
    //For everything else: do nothing
    case WS_EVT_PONG:
    {
      Serial.println("[%u] Message type: WS_EVT_PONG");
      break;
    }   
    case WS_EVT_DATA:
    {
      AwsFrameInfo * info = (AwsFrameInfo*)arg;
      if (DEBUG)
      {
        Serial.printf("[%u] Received text: %s\n", client, data);
      }
      //StaticJsonDocument<200> doc;
      DynamicJsonDocument doc(1024);
      
      uint8_t* input = data;
      DeserializationError error=deserializeJson(doc, input);
      if (error) {
        Serial.print(F("deserializeJson() failed: "));
        Serial.println(error.c_str());
        return;
      }
      //JsonObject obj = doc.as<JsonObject>();
      const char* ID = doc["ObjectID"];
      if (DEBUG)
      {      
        Serial.println(doc["ObjectID"].as<char*>());
        Serial.printf("[%u] Received ObjectID: %s\n", ID);
        /*
        const char* message = doc["message"];
        Serial.println(doc["message"].as<String>());
        Serial.printf("[%u] Received message: %s\n", message);*/
        String mes =doc["message"];
        Serial.println(mes);
        
      }
      // Toggle LED
      if (strcmp(ID,"togglePump1")==0) 
      {  
        //pumpState = pumpState ? 0 : 1;
        int Recieved_message = doc["message"];
        pumpState=Recieved_message;
        if (DEBUG)
        {           
         Serial.printf("Toggling Pump to %u\n", pumpState);
        }
      }
      // Report the state of the Pump
      else if (strcmp(ID,"getPumpState1")==0) 
      {
        if (DEBUG)
        {    
        sprintf(msg_buf, "%d", pumpState);
        Serial.printf("Sending to [%u]: %s\n", client, msg_buf);
        }
        //webSocket.sendTXT(client, msg_buf);
        client->text("Recieved get pumpstate for pump 1");
        mrunning = true;
      }
      else if (strcmp(ID,"sendPumpTime1")==0) 
      {
        int Recieved_message = doc["message"];
        settime=Recieved_message;
        if (DEBUG)
        {         
        sprintf(msg_buf, "%d", settime);
        Serial.printf("Sending to [%u]: %s\n", client, msg_buf);
        }
        //webSocket.sendTXT(client, msg_buf);
        client->text("Recieved Pump 1 time: ");
        client->text(msg_buf);
      }
      else if (strcmp(ID,"sendPumpFlow1")==0) 
      {
        int Recieved_message = doc["message"];
        setpoint=Recieved_message;
        if (DEBUG)
        {   
        sprintf(msg_buf, "%d", setpoint);
        Serial.printf("Sending to [%u]: %s\n", client, msg_buf);
        }
        client->text("Recieved Pump 1 flow: ");
        client->text(msg_buf);
        //webSocket.sendTXT(client, msg_buf);
           
      }
      else if (strcmp(ID,"sendMACAdress2")==0) 
      { 
        Serial.println("It went to sendMACAdress2 if statement"); 
        String RecAddress1 =doc["message"];
        Serial.print("Recieved message: ");
        Serial.println(RecAddress1);
        char result[6]={0xFF, 0xFF, 0xFF, 0xFF, 0xFF, 0xFF};
        MACaddress(RecAddress1,result);

        Serial.print("MAC id is: ");               
        for (int i=0; i <6; ++i)
        {
          broadcastAddress1[i]=result[i];
          Serial.print(result[i]);
          if (i!=5)  
          {       
            Serial.print(", ");
          }
        }
        Serial.println(" ");     
        //client->text(msg_buf);
        //webSocket.sendTXT(client, msg_buf);
        for (int i=0;i <6; ++i)
        {
           Serial.print(broadcastAddress1[i]);
           if(i!=5)
           {
            Serial.print(", ");
           }
        }
        Serial.println(" ");
        bool Paired=PairWithDevice(broadcastAddress1,0);
        if (Paired)
        {
          esp_now_register_send_cb(OnDataSent);
          
          client->text("Paired");
        }
        else
        {
          client->text("NotPaired");
        }
      }
      // Toggle LED
      if (strcmp(ID,"togglePump2")==0) 
      {  
        //pumpState = pumpState ? 0 : 1;
        int Recieved_message= doc["message"];
        
        if (DEBUG)
        {           
         Serial.printf("Toggling Pump 2 to %u\n",Recieved_message);
        }
        // Send message via ESP-NOW
          // Set values to send
        myData[0].ID = 3;
        myData[0].onoff = Recieved_message;
        
        // Send message via ESP-NOW
        bool res = sendData(0);
        SendMessageUser(res,client);
       
        
      }
      // Report the state of the Pump
      else if (strcmp(ID,"getPumpState2")==0) 
      {
        int Recieved_message = doc["message"];
        if (DEBUG)
        {    
          sprintf(msg_buf, "%d", Recieved_message);
          Serial.printf("Sending to [%u]: %s\n", client, msg_buf);
          client->text("Sent state ifno to Pump 2");
        }
        myData[0].ID = 4;

        // Send message via ESP-NOW
        bool res = sendData(0);
        SendMessageUser(res,client);
      }
      else if (strcmp(ID,"sendPumpTime2")==0) 
      {
        int Recieved_message = doc["message"];
        myData[0].ID = 2;
        myData[0].settime=Recieved_message;
        if (DEBUG)
        {         
          sprintf(msg_buf, "%d", Recieved_message);
          Serial.printf("Sending to [%u]: %s\n", client, msg_buf);
          client->text("Sent Pump 2 time: ");
          client->text(msg_buf);
        }
        //webSocket.sendTXT(client, msg_buf);

        bool res = sendData(0);
        SendMessageUser(res,client);
      }
      else if (strcmp(ID,"sendPumpFlow2")==0) 
      {
        int Recieved_message = doc["message"];
        myData[0].ID = 1;
        myData[0].flow=Recieved_message;
        if (DEBUG)
        {   
          sprintf(msg_buf, "%d", Recieved_message);
          Serial.printf("Sending to [%u]: %s\n", client, msg_buf);
          client->text("send pump flow to Pump 2: ");
          client->text(msg_buf);
        }

        //webSocket.sendTXT(client, msg_buf);
        bool res = sendData(0);
        SendMessageUser(res, client);
           
      }
      else if (strcmp(ID,"sendMACAdress3")==0) 
      { 
        Serial.println("It went to sendMACAdress3 if statement"); 
        String RecAddress1 =doc["message"];
        Serial.print("Recieved message: ");
        Serial.println(RecAddress1);
        char result[6]={0xFF, 0xFF, 0xFF, 0xFF, 0xFF, 0xFF};
        MACaddress(RecAddress1,result);

        Serial.print("MAC id is: ");               
        for (int i=0; i <6; ++i)
        {
          broadcastAddress2[i]=result[i];
          Serial.print(result[i]);
          if (i!=5)  
          {       
            Serial.print(", ");
          }
        }
        Serial.println(" ");     
        
        //webSocket.sendTXT(client, msg_buf);
        for (int i=0;i <6; ++i)
        {
           Serial.print(broadcastAddress2[i]);
           if(i!=5)
           {
            Serial.print(", ");
           }
        }
        Serial.println(" ");
        bool Paired=PairWithDevice(broadcastAddress2,0);
        if (Paired)
        {
          client->text("Paired2");
        }
        else
        {
          client->text("NotPaired2");
        }
      }
      // Toggle LED
      if (strcmp(ID,"togglePump3")==0) 
      { 
        int Recieved_message = doc["message"]; 
        //pumpState = pumpState ? 0 : 1;
        if (DEBUG)
        {           
         Serial.printf("Toggling Pump to %u\n", Recieved_message);
        }
        // Send message via ESP-NOW
          // Set values to send
        myData[1].ID = 3;
        myData[1].onoff = Recieved_message;
        
        // Send message via ESP-NOW
        bool res = sendData(1);
        SendMessageUser(res,client);
      }
      // Report the state of the Pump
      else if (strcmp(ID,"getPumpState3")==0) 
      {
        if (DEBUG)
        {    
          sprintf(msg_buf, "%d", "Getting Pump state for pump 3");
          Serial.printf("Sending to [%u]: %s\n", client, "Getting Pump state for pump 3");
          client->text("Getting Pump state for pump 3");
        }

        myData[1].ID = 4;
        
        // Send message via ESP-NOW
        bool res = sendData(1);
        SendMessageUser(res,client);
      }
      else if (strcmp(ID,"sendPumpTime3")==0) 
      {
        int Recieved_message = doc["message"];
        myData[1].ID = 2;
        myData[1].settime=Recieved_message;
        if (DEBUG)
        {         
          sprintf(msg_buf, "%d", Recieved_message);
          Serial.printf("Sending to [%u]: %s\n", client, msg_buf);
          client->text("Recieved pump time for pump 3: ");
          client->text(msg_buf);
        }

        bool res = sendData(1);
        SendMessageUser(res,client);
      }
      else if (strcmp(ID,"sendPumpFlow3")==0) 
      {
        int Recieved_message = doc["message"];
        myData[1].ID = 1;
        myData[1].flow=Recieved_message;
        if (DEBUG)
        {   
          sprintf(msg_buf, "%d", Recieved_message);
          Serial.printf("Sending to [%u]: %s\n", client, msg_buf);
          client->text("Recieved pump flow for pump 3: ");
          client->text(msg_buf);
        }
        
        //webSocket.sendTXT(client, msg_buf);
        bool res = sendData(1);
        SendMessageUser(res, client);
           
      }      
      // Message not recognized
      else 
      {
        Serial.println("[%u] Message not recognized");
        
      }
      break;
    }
  
    default:
    break;
  }
} 
     
/*The files which are sent from webservers memory*/
// Callback: send homepage
void onIndexRequest(AsyncWebServerRequest *request) {
  IPAddress remote_ip = request->client()->remoteIP();              
  request->send(SPIFFS, "/Index.html", "text/html");
  if (DEBUG)
  {
  Serial.println("[" + remote_ip.toString() +
                  "] HTTP GET request of " + request->url());
  }
}
 // Callback: send style sheet
void onCSSRequest(AsyncWebServerRequest *request) {
  IPAddress remote_ip = request->client()->remoteIP();
  request->send(SPIFFS, "/main.css", "text/css");
  if (DEBUG)
  {  
  Serial.println("[" + remote_ip.toString() +
                  "] HTTP GET request of " + request->url());
  } 
}
// Callback: send jquery
void onjqueyRequest(AsyncWebServerRequest *request) {
  IPAddress remote_ip = request->client()->remoteIP();
  request->send(SPIFFS, "/jquery.js", "application/js");
  if (DEBUG)
  {
  Serial.println("[" + remote_ip.toString() +
                  "] HTTP GET request of " + request->url());
  }
}
// Callback: send myJsFnctions
void onmyFunctionsRequest(AsyncWebServerRequest *request) {
  IPAddress remote_ip = request->client()->remoteIP();             
  request->send(SPIFFS, "/myJsFunctions.js", "application/js");
  if (DEBUG)
  {  
  Serial.println("[" + remote_ip.toString() +
                  "] HTTP GET request of " + request->url());
  } 
}
// Callback: send 404 if requested file does not exist
void onPageNotFound(AsyncWebServerRequest *request) {
  IPAddress remote_ip = request->client()->remoteIP();
  request->send(404, "text/plain", "Not found");
  if (DEBUG)
  {   
  Serial.println("[" + remote_ip.toString() +
                  "] HTTP GET request of " + request->url());
  } 
}

void setup() {

  // PWM for Motor
  ledcSetup(ledChannel, freq, resolution);
  ledcAttachPin(PWMPin, ledChannel);
  
  Serial.begin(115200);

  // Initialize SPIFFS
  if(!SPIFFS.begin()){
    Serial.println("An Error has occurred while mounting SPIFFS");
    while(1);
  }

  Serial.println();
  Serial.println("Configuring access point...");
    /* You can remove the password parameter if you want the AP to be open. */
  //WiFi.mode(WIFI_AP);
  WiFi.mode(WIFI_AP_STA);
  WiFi.softAP(ssid, password);// --> This line will create a WiFi hotspot.
  Serial.println("Wait 100 ms for AP_START...");
  delay(100);
  if(!WiFi.softAPConfig(local_ip, gateway, subnet)){
      Serial.println("AP Config Failed");
  }
  Serial.print("AP IP address: ");
  //Serial.println(myIP);
  Serial.println(WiFi.softAPIP());
  Serial.print("MAC address: ");
  Serial.println(WiFi.macAddress());
   // On HTTP request for root, provide index.html file
  server.on("/", HTTP_GET, onIndexRequest);
 
  // On HTTP request for style sheet, provide style.css
  server.on("/main.css", HTTP_GET, onCSSRequest);

  server.on("/jquery.js", HTTP_GET, onjqueyRequest);

  server.on("/myJsFunctions.js", HTTP_GET, onmyFunctionsRequest);

  // Handle requests for pages that do not exist
  server.onNotFound(onPageNotFound);
  // Start web server
  
  // Start WebSocket server and assign callback
  //webSocket.begin();
  webSocket.onEvent(onWebSocketEvent);
  server.addHandler(&webSocket);
  server.begin();
  Serial.println("HTTP server started");

  //setpoint = analogSacale(flow,maxAValue);
  
}

void loop() {
  int delayTime=settime*1000;
  while(pumpState == 1)
  {
    
    if (mrunning)
    {
      currentMillis = millis();
      ledcWrite(ledChannel, setpoint);
      mrunning = false;
      //Serial.println("Pump runs on the max speed");
      Serial.println("Pump running time is: ");
      Serial.println(delayTime);
      previousMillis= millis();
     }
     ledcWrite(ledChannel, setpoint);
     if (previousMillis-currentMillis >=delayTime)
     {
     mrunning = true;
     Serial.println("Job completed");
     pumpState=0;     
     break;
     }

     delay(1);

     //Waiting until time is over
     //Serial.print("Countine timer: ");
     //unsigned int long timer= (previousMillis-currentMillis)/1000;
     //Serial.println(timer);
     previousMillis = millis();
     }   
      //Serial.println("Pump runs on the zero speed");
      delay(1);
     
      ledcWrite(ledChannel, 0);
      mrunning = true;
      delay(10);
}

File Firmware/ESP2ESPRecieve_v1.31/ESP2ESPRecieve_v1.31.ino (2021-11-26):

/*
  Rui Santos
  Complete project details at https://RandomNerdTutorials.com/esp-now-esp32-arduino-ide/
  
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
  The above copyright notice and this permission notice shall be included in all
  copies or substantial portions of the Software.
*/

#include <esp_now.h>
#include <WiFi.h>

// REPLACE WITH THE MAC Address of your receiver 
uint8_t broadcastAddress[] = {0x4C, 0x11, 0xAE, 0xEA, 0xEE, 0xB4};

// Define variables to store User Input to be sent
//int flow=60;
//int settime=60;
//bool onoff=0;

const int PWMPin=26;
//int setpoint =2000; // analogvalue for flow
const int resolution = 12;
const int ledChannel = 1;
const int freq = 5000;
bool mrunning = true;
unsigned long previousMillis = 0;
unsigned long currentMillis=0;

// Define variables to store incoming readings
int incomingID=0;
int incomingflow=2000;
int incomingsettime=60; 
bool incomingonoff=0; 

// Variable to store if sending data was successful
String success;
String MacAddress;

// Structure example to receive data
// Must match the sender structure
typedef struct struct_message {
    int ID;
    int flow;
    int settime;
    bool onoff;
} struct_message;



// Create a struct_message called ESPSlave to hold the sending info
struct_message ESPSlave;

// Create a struct_message called incomingReadings
struct_message incomingReadings;

// Callback when data is sent
void OnDataSent(const uint8_t *mac_addr, esp_now_send_status_t status) {
  Serial.print("\r\nLast Packet Send Status:\t");
  Serial.println(status == ESP_NOW_SEND_SUCCESS ? "Delivery Success" : "Delivery Fail");
  if (status ==0){
    success = "Delivery Success :)";
  }
  else{
    success = "Delivery Fail :(";
  }
}
// callback function that will be executed when data is received
void OnDataRecv(const uint8_t * mac, const uint8_t *incomingData, int len) {
  memcpy(&incomingReadings, incomingData, sizeof(incomingReadings));
  Serial.print("Bytes received: ");
  Serial.println(len);
  incomingID = incomingReadings.ID; //1= flow, 2=settime 3=onoff //4 what's the pump state
  Serial.print("Incoming ID: ");
  Serial.println(incomingID); 
  if (incomingID==1)
  {
    incomingflow = incomingReadings.flow;
    Serial.print("Incoming flow: ");
    Serial.println(incomingflow); 
    
  }
  else if (incomingID==2)
  {
    incomingsettime = incomingReadings.settime;
    Serial.print("Incoming readings: ");
    Serial.println(incomingsettime); 
    
  }
  else if(incomingID==3)
  {
    incomingonoff = incomingReadings.onoff;
    Serial.print("Incoming onoff: ");
    Serial.println(incomingonoff); 
  }
  else if (incomingID==4)
  {
    //incomingonoff = incomingReadings.onoff;
    //Serial.print("Incoming onoff: ");
    //Serial.println(incomingonoff); 
     Serial.print("Requested Pump state was asked");
     
     //Serial.println(incomingonoff); 
     ESPSlave.ID=1; //update
     ESPSlave.flow = incomingflow;
     ESPSlave.settime = incomingsettime;
     ESPSlave.onoff = incomingonoff;
     // Send message via ESP-NOW
     esp_err_t result = esp_now_send(broadcastAddress, (uint8_t *) &ESPSlave, sizeof(ESPSlave));  
  }
  
  
}
 
void setup() {
  analogSetWidth(12); //12 bit resolution for ADC writing
  ledcSetup(ledChannel, freq, resolution);
  ledcAttachPin(PWMPin, ledChannel);
  // Initialize Serial Monitor
  Serial.begin(115200);
  
  // Set device as a Wi-Fi Station
  WiFi.mode(WIFI_STA);

  // Init ESP-NOW
  if (esp_now_init() != ESP_OK) {
    Serial.println("Error initializing ESP-NOW");
    return;
  }
  else {
    Serial.println("ESP-NOW initialized");    
  }
  // Once ESPNow is successfully Init, we will register for Send CB to
  // get the status of Trasnmitted packet
  esp_now_register_send_cb(OnDataSent);
  
    // Register peer
  esp_now_peer_info_t peerInfo;
  memcpy(peerInfo.peer_addr, broadcastAddress, 6);
  peerInfo.channel = 0;  
  peerInfo.encrypt = false;
  
  // Add peer        
  if (esp_now_add_peer(&peerInfo) != ESP_OK){
    Serial.println("Failed to add peer");
    return;
  }
  
  // Once ESPNow is successfully Init, we will register for recv CB to
  esp_now_register_recv_cb(OnDataRecv);
    
  MacAddress = WiFi.macAddress();
  Serial.println("macAddress is: ");
  Serial.println(MacAddress);
  
}
 
void loop() {
  int delayTime=incomingsettime*1000;
  while(incomingonoff == 1)
  {
    if (mrunning)
    {
      currentMillis = millis();
      ledcWrite(ledChannel, incomingflow);
      mrunning = false;
      Serial.println("Pump runs on the max speed");
      Serial.println("Pump running time is: ");
      Serial.println(delayTime);
      previousMillis= millis();
    }
     ledcWrite(ledChannel, incomingflow);
     if (previousMillis-currentMillis >=delayTime)
     {
       mrunning = true;
       Serial.println("Job completed");
       incomingonoff=0;
       // Set values to send
       ESPSlave.ID=1; //update
       ESPSlave.flow = incomingflow;
       ESPSlave.settime = incomingsettime;
       ESPSlave.onoff = incomingonoff;
       // Send message via ESP-NOW
       esp_err_t result = esp_now_send(broadcastAddress, (uint8_t *) &ESPSlave, sizeof(ESPSlave));     
       break;
     }
     delay(1);
     //Waiting until time is over
     //Serial.print("Countine timer: ");
     //unsigned int long timer= (previousMillis-currentMillis)/1000;
     //Serial.println(timer);
     previousMillis = millis();
   }   
    //Serial.println("Pump runs on the zero speed");
    delay(1);
   
    ledcWrite(ledChannel, 0);
    mrunning = true;
  /*
  // Set values to send
  ESPSlave.flow = flow;
  ESPSlave.settime = settime;
  ESPSlave.onoff = onoff;
  
  // Send message via ESP-NOW
  esp_err_t result = esp_now_send(broadcastAddress, (uint8_t *) &ESPSlave, sizeof(ESPSlave));
  
  if (result == ESP_OK) {
    Serial.println("Sent with success");
  }
  else {
    Serial.println("Error sending the data");
  }*/
  /*
  delay(1000);
  Serial.print("ID: ");
  Serial.println(incomingID);
  Serial.print("flow: ");
  Serial.println(incomingflow);
  Serial.print("Settime: ");
  Serial.println(incomingsettime);
  Serial.print("Onoff: ");
  Serial.println(incomingonoff);
  Serial.println();*/
}
